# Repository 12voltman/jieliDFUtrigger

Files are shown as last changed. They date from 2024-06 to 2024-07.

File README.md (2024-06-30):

# USB-C dongle for triggering DFU mode on Jieli-Tech microcontrollers  
These chips are primarily programmed over USB 2.0, and appear as mass-storage devices.  However, they do not have a traditional reset button and rely on a specific bit pattern being presented on the USB data lines.  
This project pulls heavily from the excellent research of @christian-kramer [here](https://github.com/christian-kramer/JieLi-AC690X-Familiarization).  

## How to use
TBD, will always let you trigger DFU using onboard button, may also have optional modes to automatically enter DFU when plugging in a board.

## Alternate uses
This board also breaks out some of the secondary USB-C lines (the CC and SBU pins) to a header, so you can use it to probe those lines.  
Several of my boards also use these lines for non-standard uses in ways that ideally don't conflict with the USB-C specifications.  Some examples include battery level monitoring, onewire debug, and firmware upload.  
In particular, some of my boards that inclue a modern ATTINY processor (including this one) bring the single wire programming interface (UPDI) out to the SBU pins of the female USB-C connector, so if I ever have to make 1000 of them I can upload the firmware with a tool such as this.  
For this application, and for updating the firmware of the ATTINY412 on this board, you can use a tool such as the [LV UPDI Friend](https://www.adafruit.com/product/5879) or [HV UPDI Friend](https://www.adafruit.com/product/5893) from Adafruit.  
For updating the onboard MCU, connect as following (UPDI Friend to this board) VCC to +, GND to -, and UPDI to the test point labeled UPDI.  
For using this tool with a UPDI Friend to update another board connected to it, connect as following, VCC to + (do not connect if powering over USB), GND to -, UPDI to SBU1.

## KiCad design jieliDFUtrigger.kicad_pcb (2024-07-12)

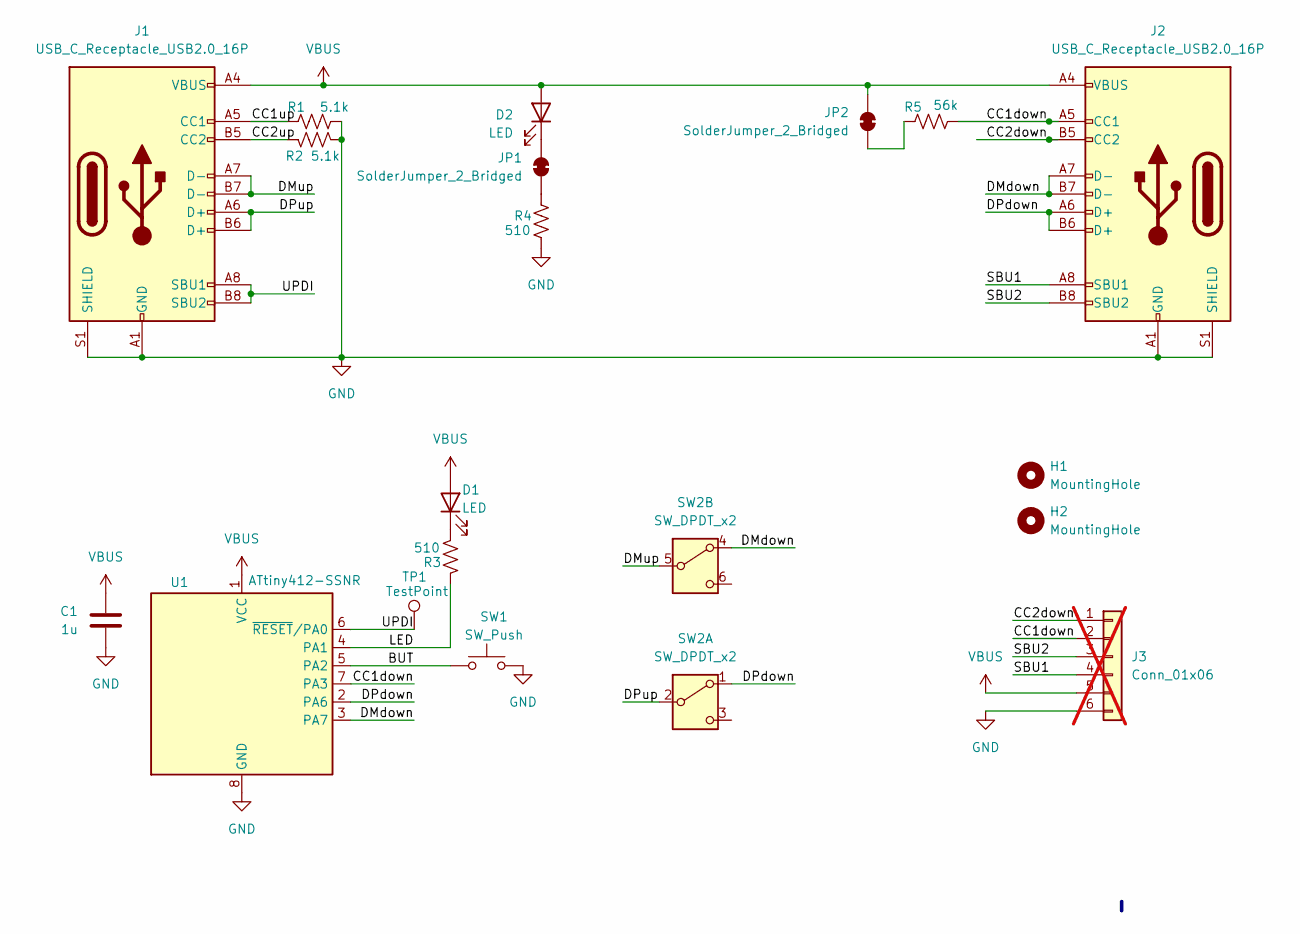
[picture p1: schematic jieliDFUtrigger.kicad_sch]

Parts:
C1: 1u; C_0402_1005Metric; LCSC C52923
D1: LED; LED_0402_1005Metric; LCSC C2856703
D2: LED; LED_0402_1005Metric; LCSC C965790
H1, H2: MountingHole; MountingHole_3.2mm_M3
J1: USB_C_Receptacle_USB2.0_16P; USB_C_Receptacle_HCTL_HC-TYPE-C-16P-01A; LCSC C2765186
J2: USB_C_Receptacle_USB2.0_16P; USB_C_PLUG_VERT_YTC-TC16S-128; LCSC C2927282
J3: Conn_01x06; PinHeader_1x06_P2.54mm_Vertical; LCSC C37208; not fitted
JP1, JP2: SolderJumper_2_Bridged; SolderJumper-2_P1.3mm_Bridged_RoundedPad1.0x1.5mm
R1, R2: 5.1k; R_0402_1005Metric; LCSC C25905
R3, R4: 510; R_0402_1005Metric; LCSC C25123
R5: 56k; R_0402_1005Metric; LCSC C25796
SW1: SW_Push; TINYTACTILE; LCSC C455280
SW2: SW_DPDT_x2; DPDT-Slide_top; LCSC C2837066
TP1: TestPoint; TestPoint_Pad_D3.0mm
U1: ATtiny412-SSNR; SOIC-8_3.9x4.9mm_P1.27mm; LCSC C1337190

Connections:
/BUT: SW1.1, U1.5 (PA2)
/CC1down: J2.A5 (CC1), J3.2, R5.2, U1.7 (PA3)
/CC1up: J1.A5 (CC1), R1.1
/CC2down: J2.B5 (CC2), J3.1
/CC2up: J1.B5 (CC2), R2.1
/DMdown: J2.A7 (D-), J2.B7 (D-), SW2.4 (A), U1.3 (PA7)
/DMup: J1.A7 (D-), J1.B7 (D-), SW2.5 (B)
/DPdown: J2.A6 (D+), J2.B6 (D+), SW2.1 (A), U1.2 (PA6)
/DPup: J1.A6 (D+), J1.B6 (D+), SW2.2 (B)
/LED: R3.2, U1.4 (PA1)
/SBU1: J2.A8 (SBU1), J3.4
/SBU2: J2.B8 (SBU2), J3.3
/UPDI: J1.A8 (SBU1), J1.B8 (SBU2), TP1.1, U1.6 (~RESET/PA0)
GND: C1.2, J1.A1 (GND), J1.A12 (GND), J1.B1 (GND), J1.B12 (GND), J1.S1 (SHIELD), J2.A1 (GND), J2.A12 (GND), J2.B1 (GND), J2.B12 (GND), J2.S1 (SHIELD), J3.6, R1.2, R2.2, R4.1, SW1.2, U1.8 (GND)
unnamed: D1.1 (K), R3.1
unnamed: D2.1 (K), JP1.1 (A)
unnamed: JP1.2 (B), R4.2
unnamed: JP2.2 (B), R5.1
VBUS: C1.1, D1.2 (A), D2.2 (A), J1.A4 (VBUS), J1.A9 (VBUS), J1.B4 (VBUS), J1.B9 (VBUS), J2.A4 (VBUS), J2.A9 (VBUS), J2.B4 (VBUS), J2.B9 (VBUS), J3.5, JP2.1 (A), U1.1 (VCC)

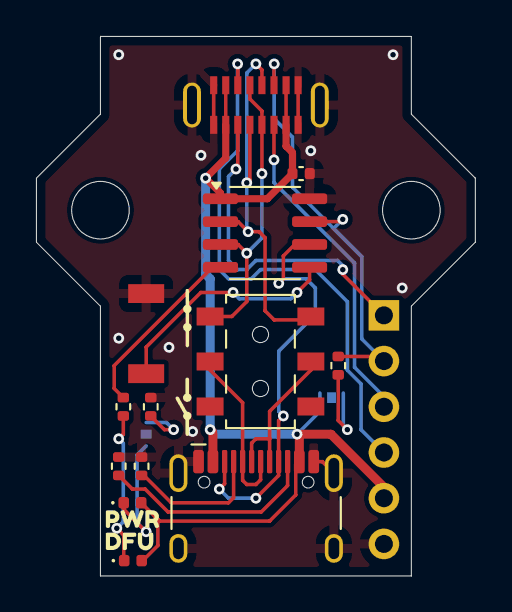
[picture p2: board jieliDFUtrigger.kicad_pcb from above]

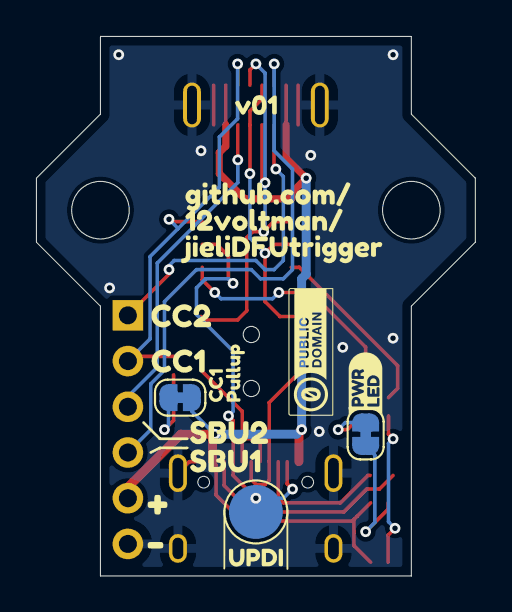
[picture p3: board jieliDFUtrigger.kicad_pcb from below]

Board: 2 copper layers, 24.4 x 30.0 mm, 29 parts (12 on the bottom side), 19 nets.

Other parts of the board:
kibuzzard-6680AAC4: G***; kibuzzard-6680AAC4
kibuzzard-668124E2: G***; kibuzzard-668124E2
kibuzzard-668145FF: G***; kibuzzard-668145FF
kibuzzard-668146A2: G***; kibuzzard-668146A2
kibuzzard-668148BC: G***; kibuzzard-668148BC
kibuzzard-6681489B: G***; kibuzzard-6681489B
kibuzzard-66814327: G***; kibuzzard-66814327
kibuzzard-66814765: G***; kibuzzard-66814765
kibuzzard-66814857: G***; kibuzzard-66814857
kibuzzard-66814893: G***; kibuzzard-66814893

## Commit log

2024-06-30 Initial PCB files
    [jieliDFUtrigger.kicad_pcb, jieliDFUtrigger.kicad_sch]
2024-07-01 Minor oversights
    [jieliDFUtrigger.kicad_pcb, jieliDFUtrigger.kicad_sch]
2024-07-12 Changed parts
    [jieliDFUtrigger.kicad_pcb, jieliDFUtrigger.kicad_sch]
